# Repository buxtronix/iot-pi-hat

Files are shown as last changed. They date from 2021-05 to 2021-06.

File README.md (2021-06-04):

# IoT Pi i/o Hat

A board providing easy access to USB, power and other ports of
the Raspberry Pi compatible board available from my amateur radio
club, VK2BV.

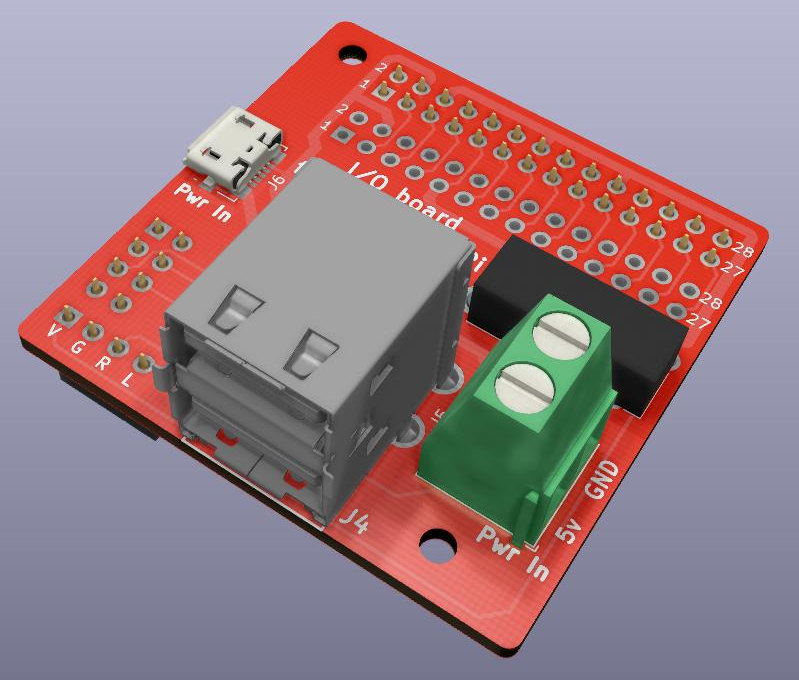
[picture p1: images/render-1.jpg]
Render Board render


# Features

 * Provides power via Micro-USB or screw terminals
 * Easy access to USB ports
 * USB ports are powered directly, not via the Pi board
 * A/V pins broken out
 * Extra header pins for connecting to the GPIO pins

# BoM

| Description + link | Unit price (AUD) |
| --- | --- |
| PCB (any Fab house)|  ~ $1 |
| [Dual USB socket](https://au.rs-online.com/web/p/usb-connectors/8006848/) | $2.34 |
| [Micro USB socket](https://au.rs-online.com/web/p/usb-connectors/7025475/) | $1.85 |
| [Polyfuse](https://au.rs-online.com/web/p/resettable-surface-mount-fuses/6478409/) | $0.42 |
| [3.5mm jack](https://au.rs-online.com/web/p/jack-plugs-sockets/8051668/) | $2.06 |
| 5mm screw terminal | ~ $0.40 |
| PCB header strips | ~ $0.40 |

# Schematic

See [iot-board-hat.pdf](https://raw.githubusercontent.com/buxtronix/iot-pi-hat/master/iot-board-hat.pdf)

# Assembly

Assembly is quite straight forward, see the [pictures](images/) for views
of where the parts fit.

The bottom of the board contains the female headers, all other parts are
on the top. Ensure the 28-pin header goes against the board edge (J1/Pi),
not the other 28-pin spot which is available for expansion use.

# Usage

Power is supplied either via the screw terminals, or the micro-USB
connector. For (semi-)permanent installtion, the screw terminals are
recommended as Micro-USB can be less reliable. Be sure to supply only
5v as there is no regulator, nor is there polarity protection.

The poly-fuse protects against overcurrent draw from USB peripherals. If
the fuse is problematic (eg too much voltage drop) you can bypass it by
soldering a bridge across JP1.

The A/V jack follows the connectivity standard per the RPi3+ as well as many
TRRS cables. [See details](https://www.raspberrypi-spy.co.uk/2014/07/raspberry-pi-model-b-3-5mm-audiovideo-jack/)

# Contact

Ben Buxton (bbuxton@gmail.com)

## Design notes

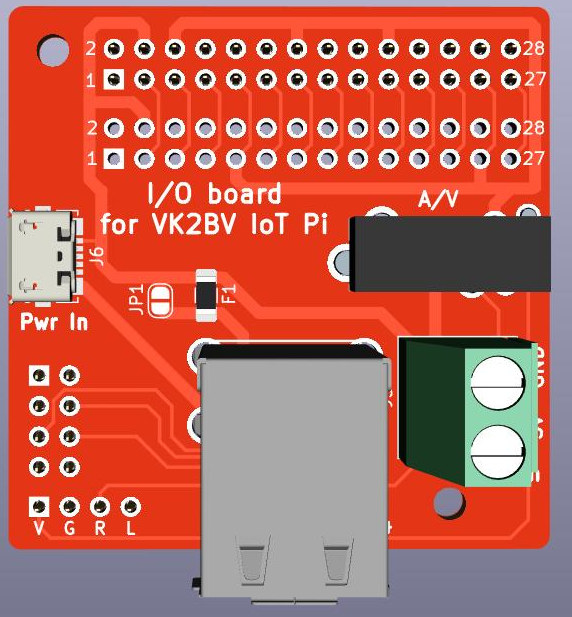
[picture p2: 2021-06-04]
images/render-2.jpg

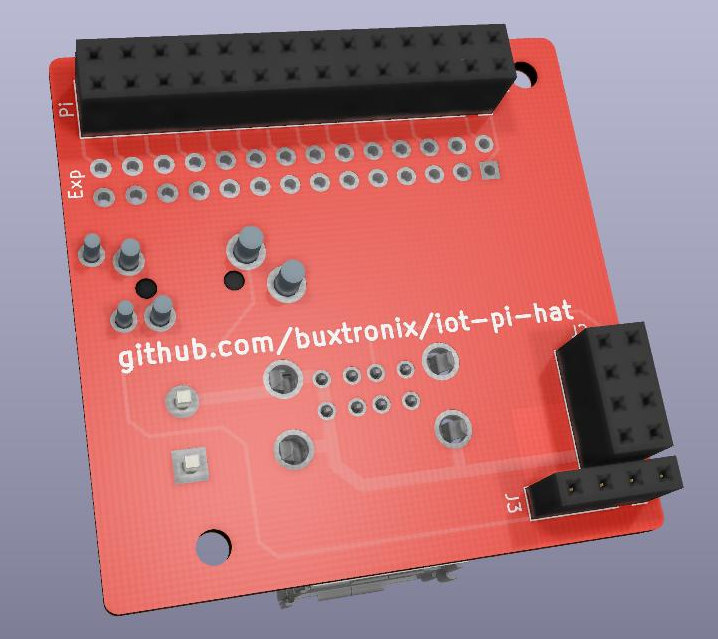
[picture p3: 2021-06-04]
images/render-3.jpg

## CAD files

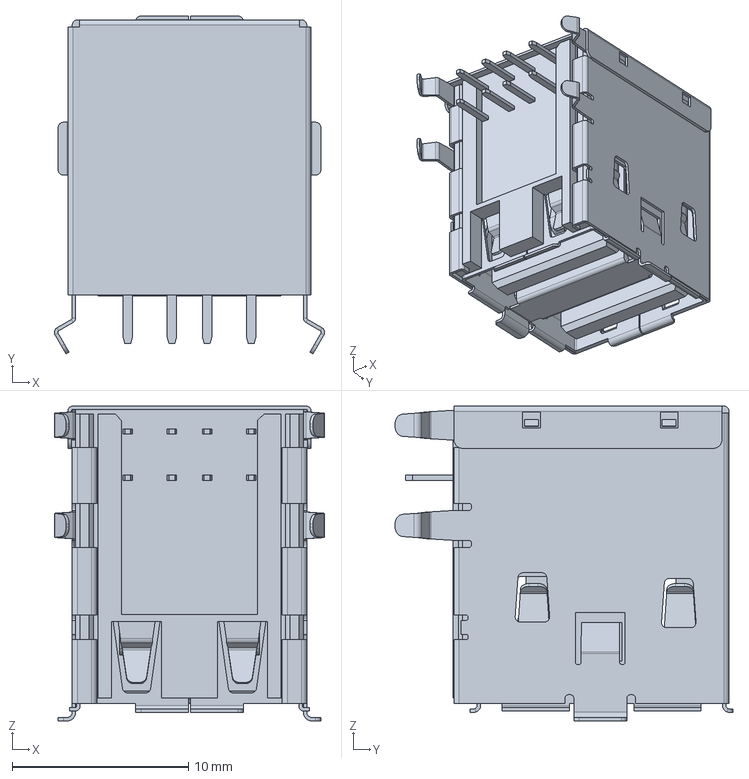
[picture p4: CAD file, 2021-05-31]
3d/67298-3090.stp
15.3 x 19.2 x 17.9 mm

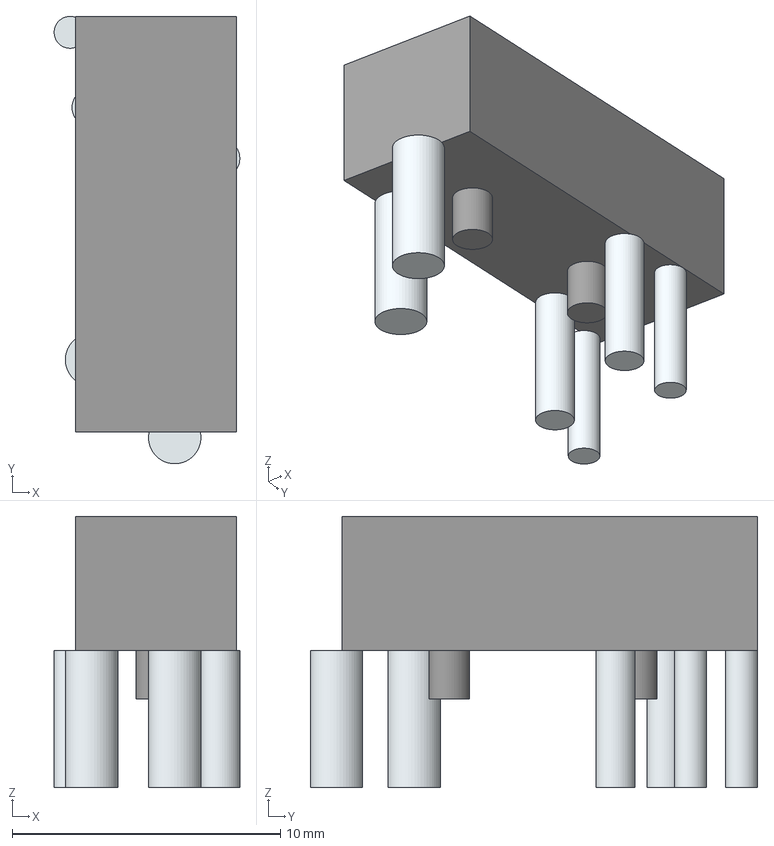
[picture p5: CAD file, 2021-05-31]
3d/FC68127.stp
6.92 x 16.7 x 10.1 mm
Lugs x 8
Leads x 8

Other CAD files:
3d/FC68127.stl

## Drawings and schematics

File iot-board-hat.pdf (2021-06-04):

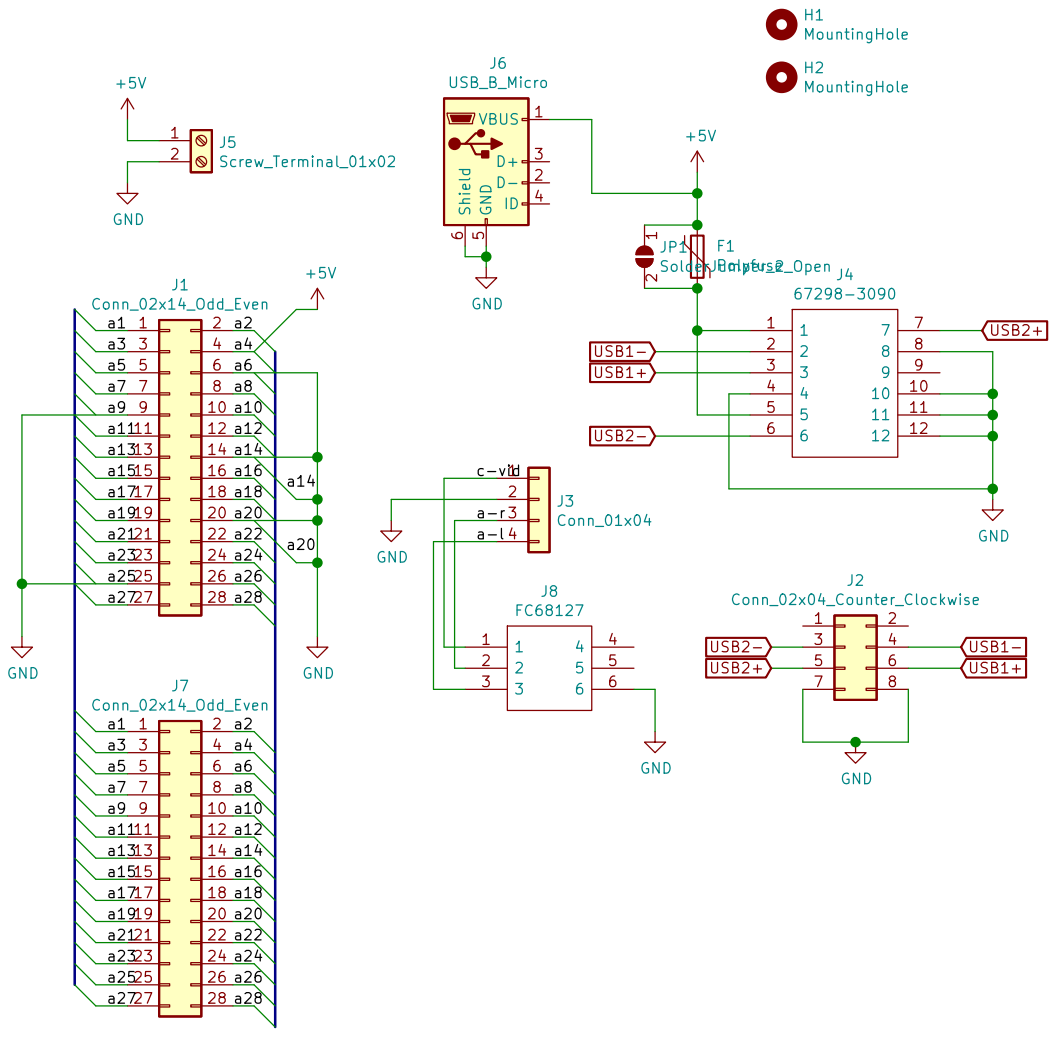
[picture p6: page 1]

Id: 1/1 Title: File: iot-board-hat.sch Sheet: /

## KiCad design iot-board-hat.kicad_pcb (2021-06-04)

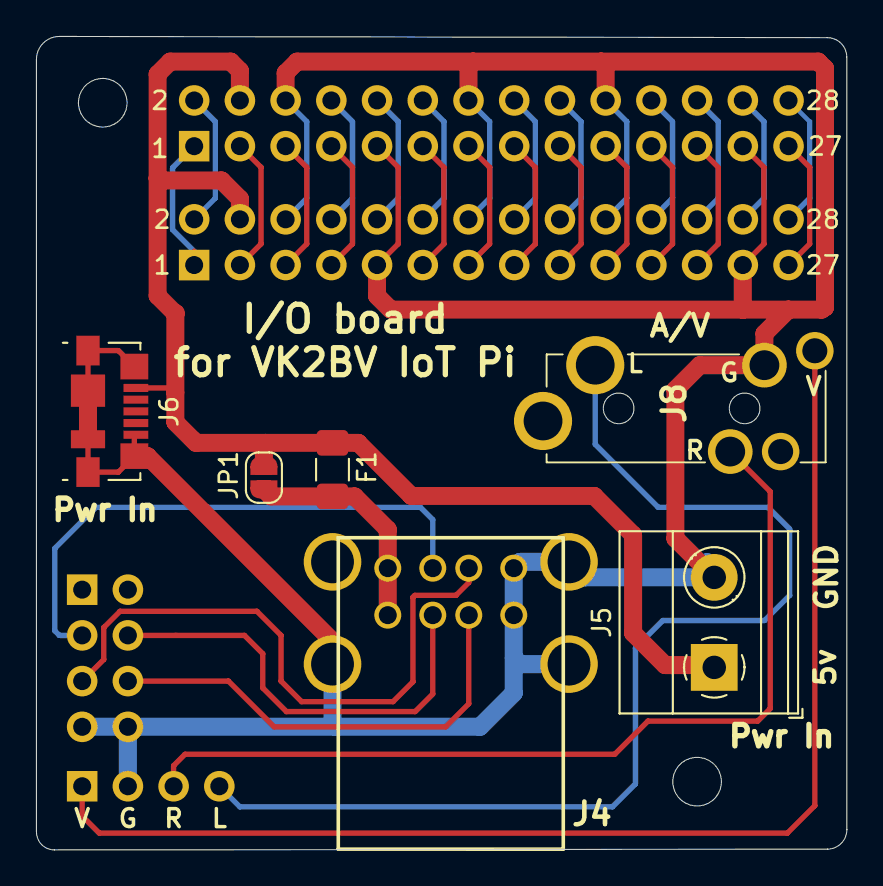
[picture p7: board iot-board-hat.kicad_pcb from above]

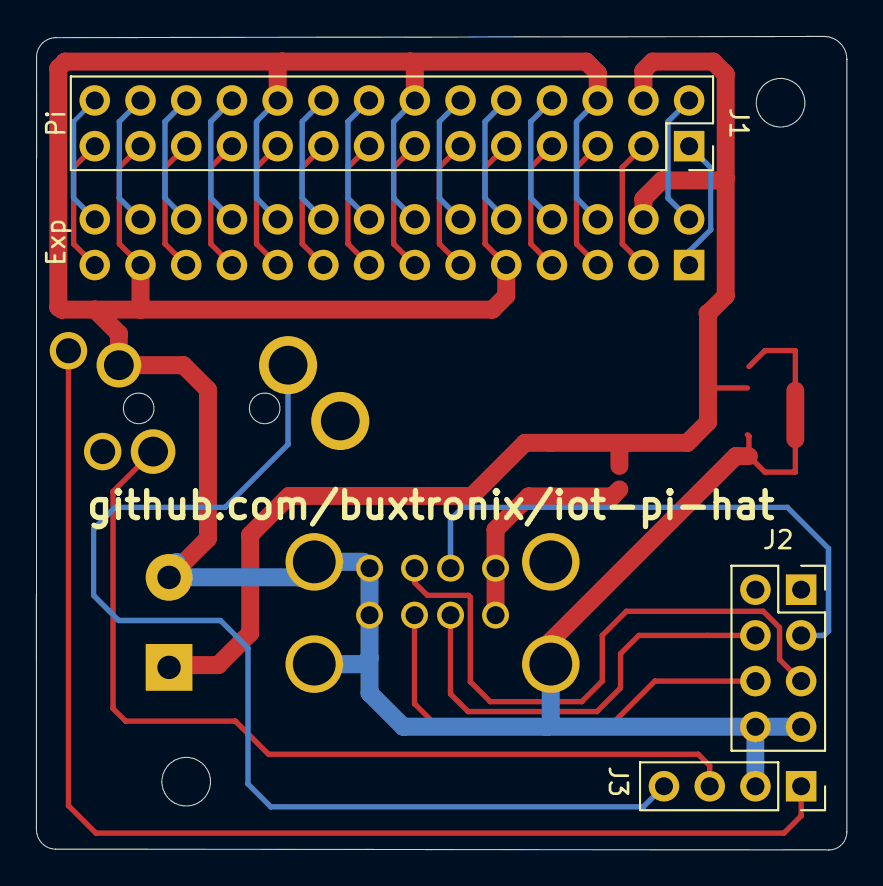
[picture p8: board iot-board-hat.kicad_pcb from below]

Board: 2 copper layers, 45.0 x 45.2 mm, 12 parts (4 on the bottom side), 32 nets.

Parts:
F1: Polyfuse; Fuse_1206_3216Metric_Pad1.42x1.75mm_HandSolder
H1, H2: MountingHole; MountingHole_2.7mm_M2.5_ISO7380
J1, J7: Conn_02x14_Odd_Even; PinSocket_2x14_P2.54mm_Vertical
J2: Conn_02x04_Counter_Clockwise; PinSocket_2x04_P2.54mm_Vertical
J3: Conn_01x04; PinSocket_1x04_P2.54mm_Vertical
J4: 67298-3090; MOLEX-DUALUSB
J5: Screw_Terminal_01x02; TerminalBlock_Phoenix_MKDS-1,5-2_1x02_P5.00mm_Horizontal
J6: USB_B_Micro; USB_Micro-B_Molex_47346-0001
J8: FC68127
JP1: SolderJumper_2_Open; SolderJumper-2_P1.3mm_Open_RoundedPad1.0x1.5mm

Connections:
+5V: F1.2, J1.4, J5.1, J6.1, J7.4, JP1.1
/a1: J1.1, J7.1
/a2: J1.2, J7.2
/a3: J1.3, J7.3
/a5: J1.5, J7.5
/a7: J1.7, J7.7
/a8: J1.8, J7.8
/a10: J1.10, J7.10
/a11: J1.11, J7.11
/a12: J1.12, J7.12
/a13: J1.13, J7.13
/a15: J1.15, J7.15
/a16: J1.16, J7.16
/a17: J1.17, J7.17
/a18: J1.18, J7.18
/a19: J1.19, J7.19
/a21: J1.21, J7.21
/a22: J1.22, J7.22
/a23: J1.23, J7.23
/a24: J1.24, J7.24
/a26: J1.26, J7.26
/a27: J1.27, J7.27
/a28: J1.28, J7.28
/a-l: J3.4, J8.3
/a-r: J3.3, J8.2
/c-vid: J3.1, J8.1
GND: J1.6, J1.9, J1.14, J1.20, J1.25, J2.7, J2.8, J3.2, J4.4, J4.8, J4.10, J4.11, J4.12, J5.2, J6.5, J6.6, J7.6, J7.9, J7.14, J7.20, J7.25, J8.6
unnamed: F1.1, J4.1, J4.5, JP1.2
USB1+: J2.6, J4.3
USB1-: J2.4, J4.2
USB2+: J2.5, J4.7
USB2-: J2.3, J4.6

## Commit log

2021-05-31 add schematic pdf
2021-05-31 some tweaks
    [iot-board-hat.kicad_pcb]
2021-06-04 Various updates/tweaks
    [iot-board-hat.kicad_pcb, iot-board-hat.sch]
